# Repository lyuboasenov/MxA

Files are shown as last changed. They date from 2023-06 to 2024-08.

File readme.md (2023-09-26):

# MxA

MxA is a portable BLE-enabled strain gauge that can be used for weight-free training as well as testing/assessment.

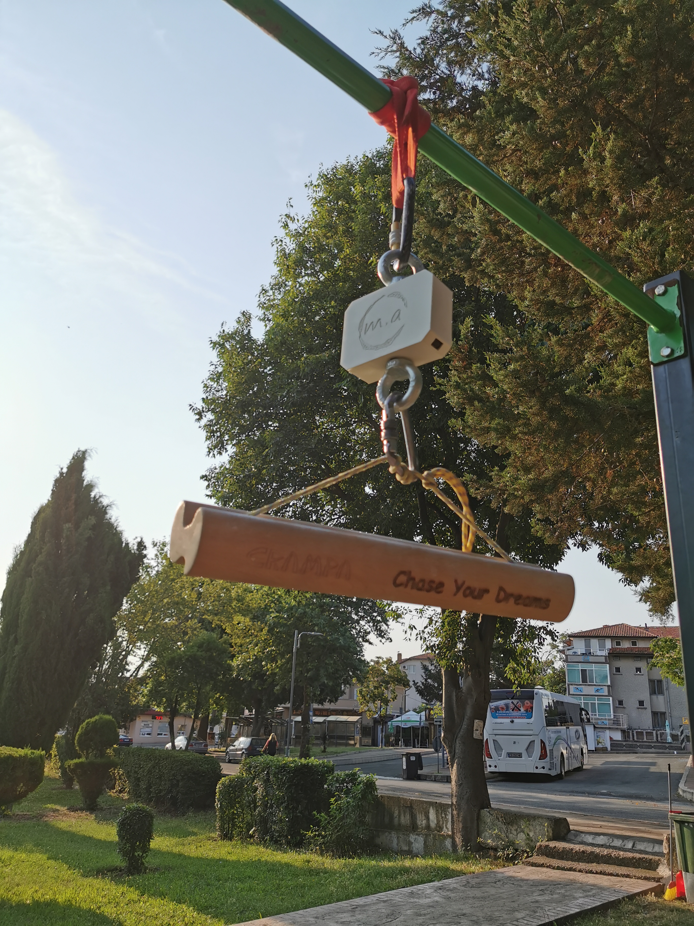
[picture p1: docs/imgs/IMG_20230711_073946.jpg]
In action


## Hardware technical specification

The hardware is based on ESP32-WROOM module, HX711 amplifier and S-type strain gauge.

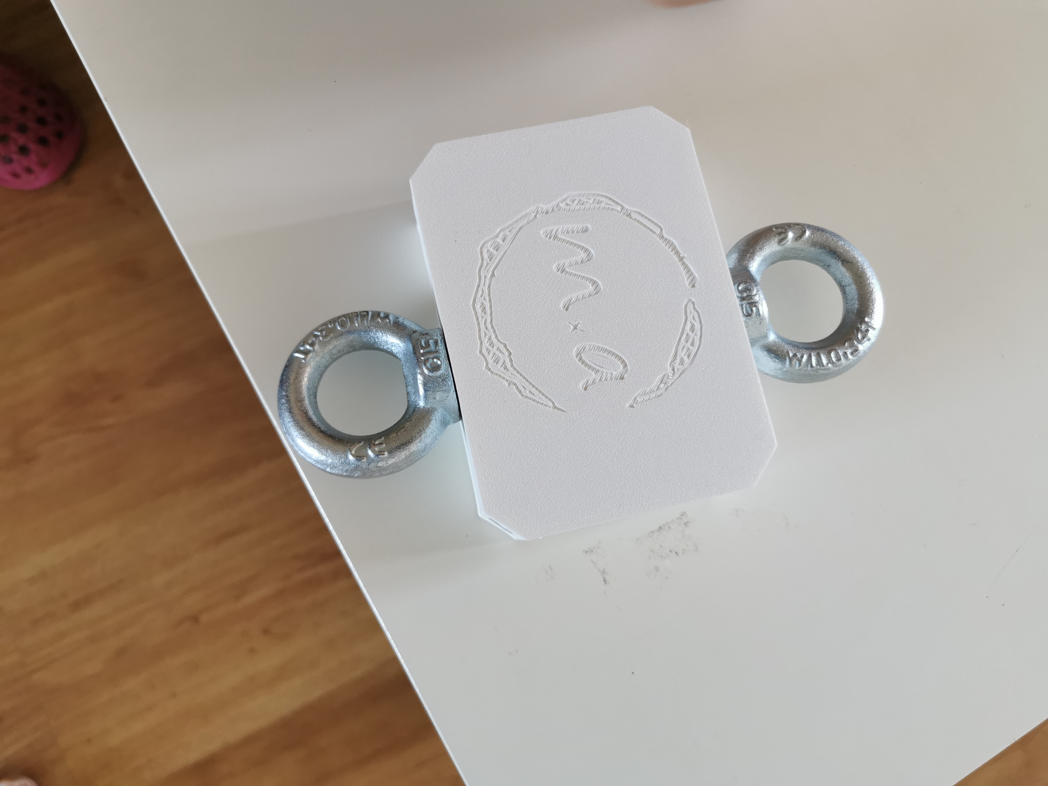
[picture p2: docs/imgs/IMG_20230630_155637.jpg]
Assembled device

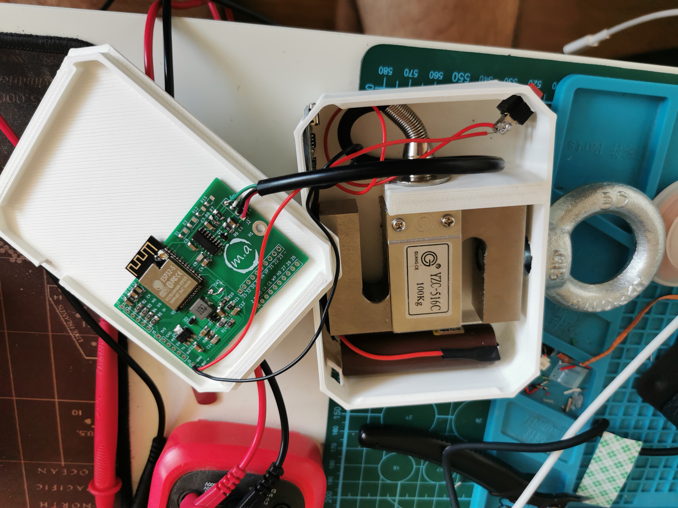
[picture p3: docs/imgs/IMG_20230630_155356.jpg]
Opened


[Read more...](docs/hardware.md)

**DIY** You can assemble the device from pre-built modules
[DIY](docs/diy.md)

## Firmware

[Read more...](docs/firmware.md)

## Mobile application

*TBA*

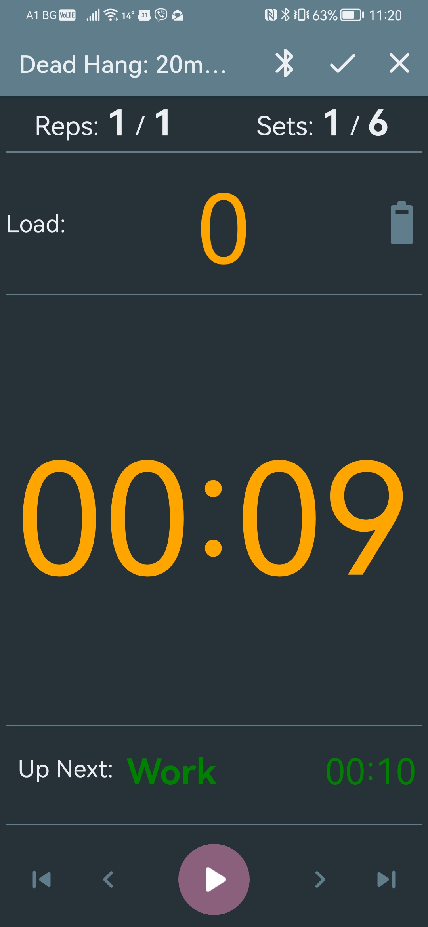
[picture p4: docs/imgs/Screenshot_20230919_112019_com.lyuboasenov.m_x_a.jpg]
Timer

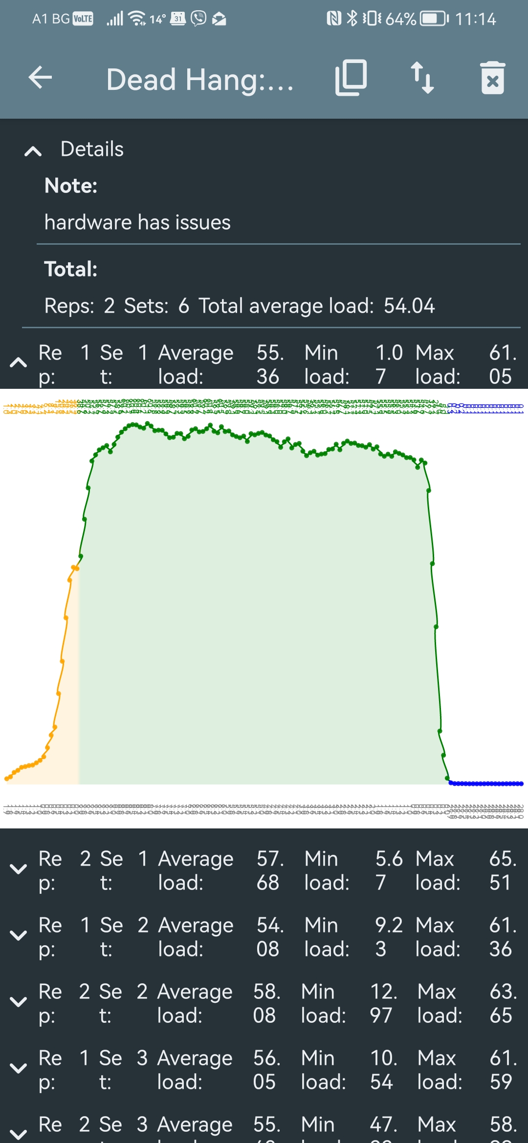
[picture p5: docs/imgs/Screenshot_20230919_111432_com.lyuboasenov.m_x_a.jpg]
Repetition diagram


[Read more...](docs/mobile-app.md)

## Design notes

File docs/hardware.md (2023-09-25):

# Hardware

The hardware is based on [ESP32-WROOM module](https://www.aliexpress.com/item/32840441199.html), [HX711](https://www.aliexpress.com/item/1005004493775451.html) amplifier and [S-type strain gauge](https://www.aliexpress.com/item/32866914213.html).

The power is supplied by a single [18650 battery](https://www.aliexpress.com/item/32821524948.html) and a [TP4056 module](https://www.aliexpress.com/item/1005004427739715.html) for battery charging.

## Schematic

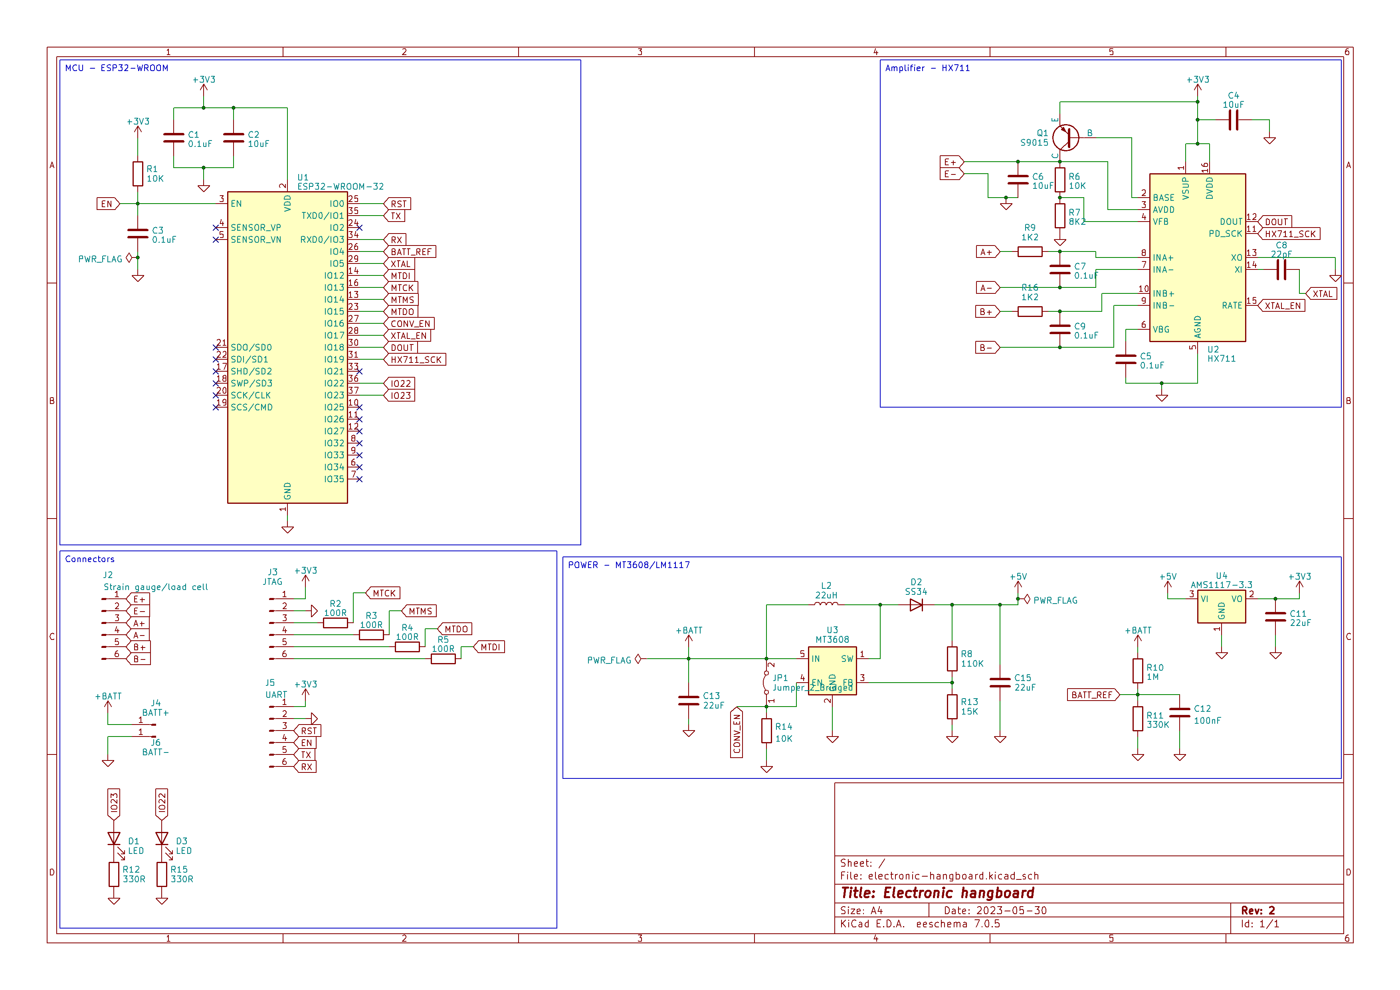
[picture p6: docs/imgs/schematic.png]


## PCB

### PCB v2 image

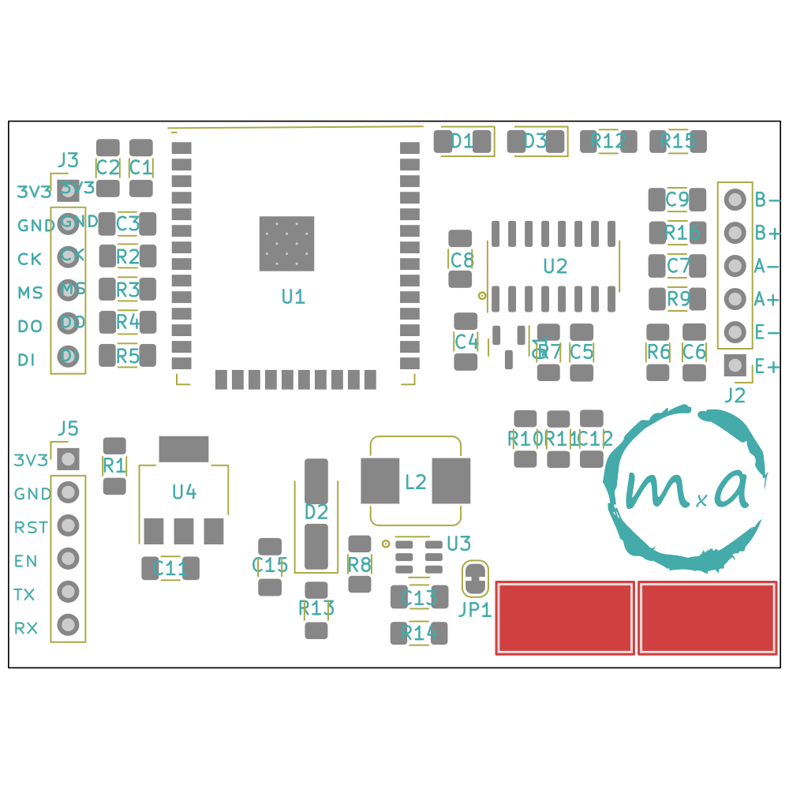
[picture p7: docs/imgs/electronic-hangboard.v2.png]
Board image


### Old PCB revisions

PCB old - white + new - green

## HX711

Increasing HX711 sampling rate [youtube](https://www.youtube.com/watch?v=Rp_M0NbDSpo)

## BOM

null|Sourced|Value|Footprint|Quantity|
|---|-------|-----|---------|--------|
1|C1, C3, C5, C7, C9, C12|100nF|C_1206_3216Metric_Pad1.33x1.80mm_HandSolder|6
2|C2, C4, C6|10uF|C_1206_3216Metric_Pad1.33x1.80mm_HandSolder|3
3|C11, C13, C15|22uF|C_1206_3216Metric_Pad1.33x1.80mm_HandSolder|3
4|C8|22pF|C_1206_3216Metric_Pad1.33x1.80mm_HandSolder|1
5|R2, R3, R4, R5|100R|R_1206_3216Metric_Pad1.30x1.75mm_HandSolder|4
6|R1, R6, R14|10K|R_1206_3216Metric_Pad1.30x1.75mm_HandSolder|3
7|R9, R16|1K2|R_1206_3216Metric_Pad1.30x1.75mm_HandSolder|2
8|R12, R15|330R|R_1206_3216Metric_Pad1.30x1.75mm_HandSolder|2
9|R7|8K2|R_1206_3216Metric_Pad1.30x1.75mm_HandSolder|1
10|R8|110K|R_1206_3216Metric_Pad1.30x1.75mm_HandSolder|1
11|R10|1M|R_1206_3216Metric_Pad1.30x1.75mm_HandSolder|1
12|R11|330K|R_1206_3216Metric_Pad1.30x1.75mm_HandSolder|1
13|R13|15K|R_1206_3216Metric_Pad1.30x1.75mm_HandSolder|1
14|L2|22uH|L_Bourns_SRP7028A_7.3x6.6mm|1
15|D1, D3|LED|D_1206_3216Metric_Pad1.42x1.75mm_HandSolder|2
16|D2|SS34|D_SMA_Handsoldering|1
17|U1|ESP32-WROOM-32|ESP32-WROOM-32|1
18|U2|HX711|SOP-16_3.9x9.9mm_P1.27mm|1
19|U3|MT3608|SOT-23-6|1
20|U4|AMS1117-3.3|SOT-223-3_TabPin2|1
21|JP1|Jumper_2_Bridged|SolderJumper-2_P1.3mm_Bridged_RoundedPad1.0x1.5mm|1
22|Q1|S9015|SOT-23|1
23|J4, J6|Conn_01x01_Pin|SolderWirePad_1x01_SMD_5x10mm|2
24|J2|Conn_01x04_Pin|PinHeader_1x06_P2.54mm_Vertical|1
25|J3|JTAG|PinHeader_1x06_P2.54mm_Vertical|1
26|J5|UART|PinHeader_1x06_P2.54mm_Vertical|1

## Images

Assembled device
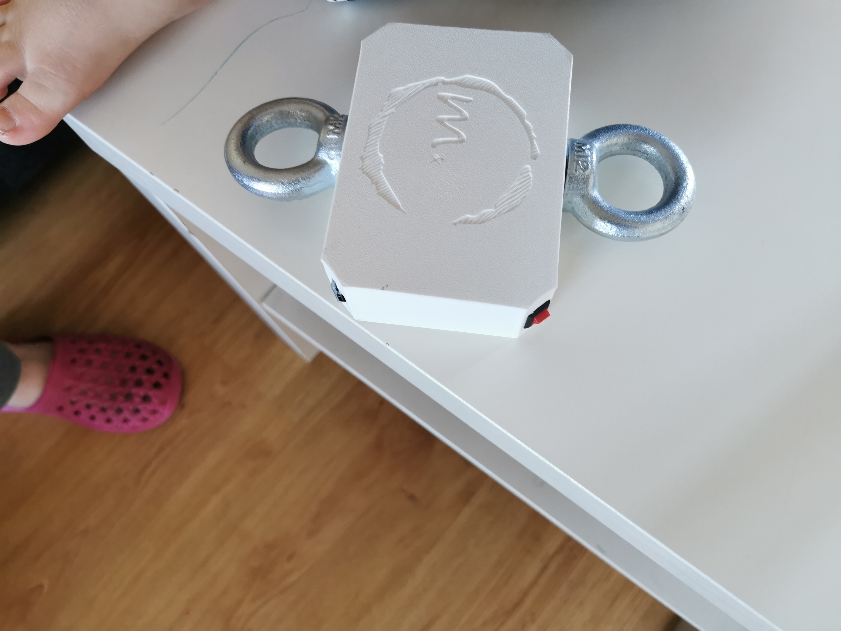
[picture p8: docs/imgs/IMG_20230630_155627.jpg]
Assembled device 2

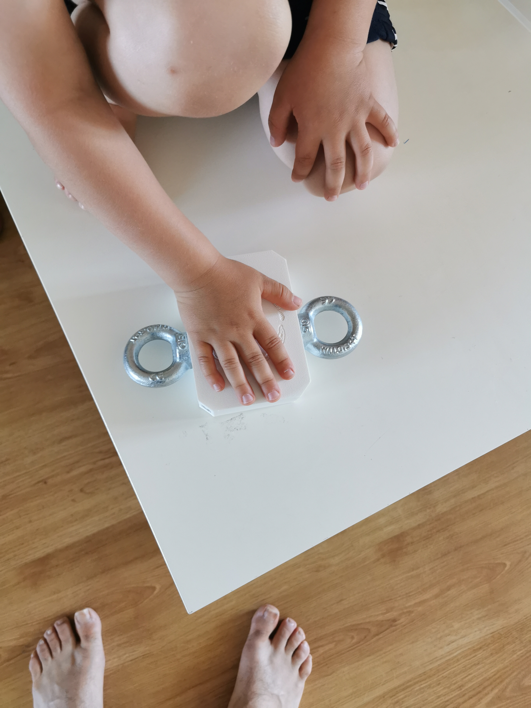
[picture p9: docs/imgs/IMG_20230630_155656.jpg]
Size reference

Opened
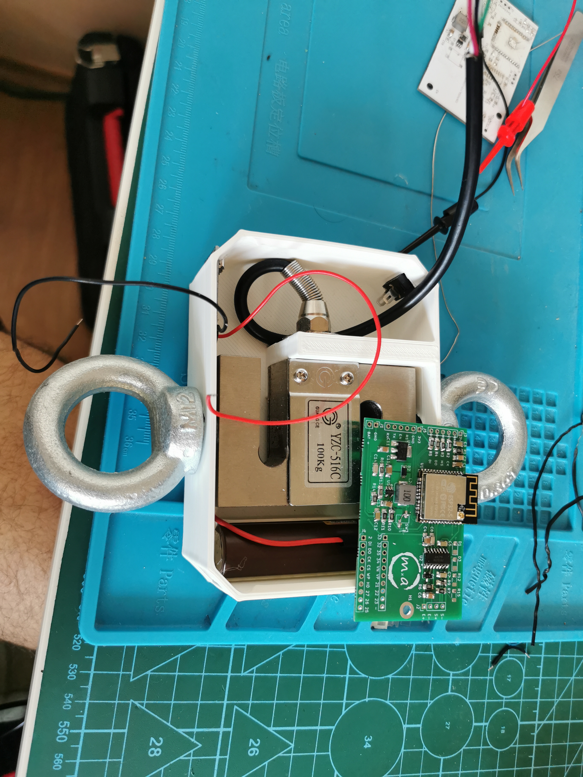
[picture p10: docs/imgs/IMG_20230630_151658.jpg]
Opened 2

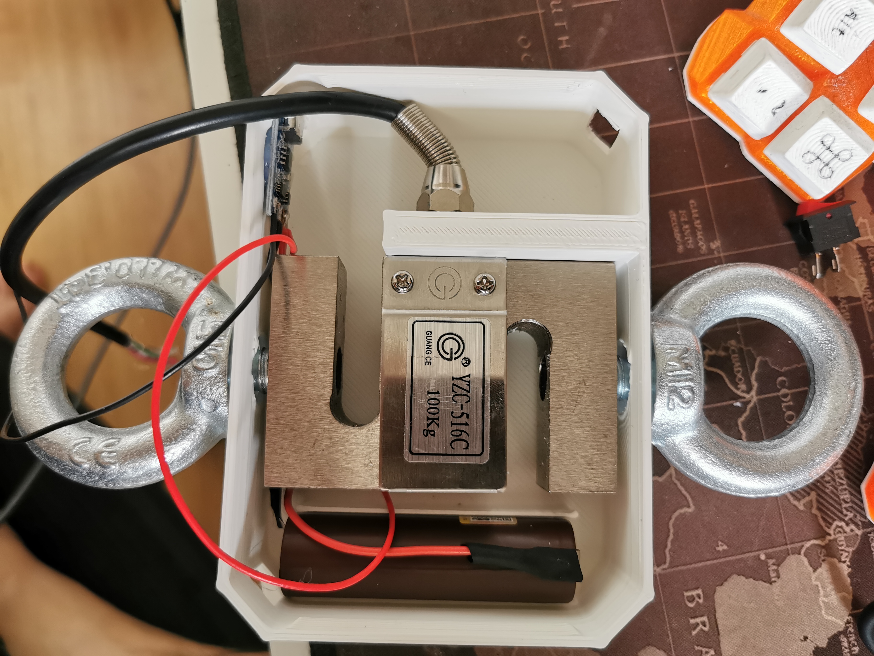
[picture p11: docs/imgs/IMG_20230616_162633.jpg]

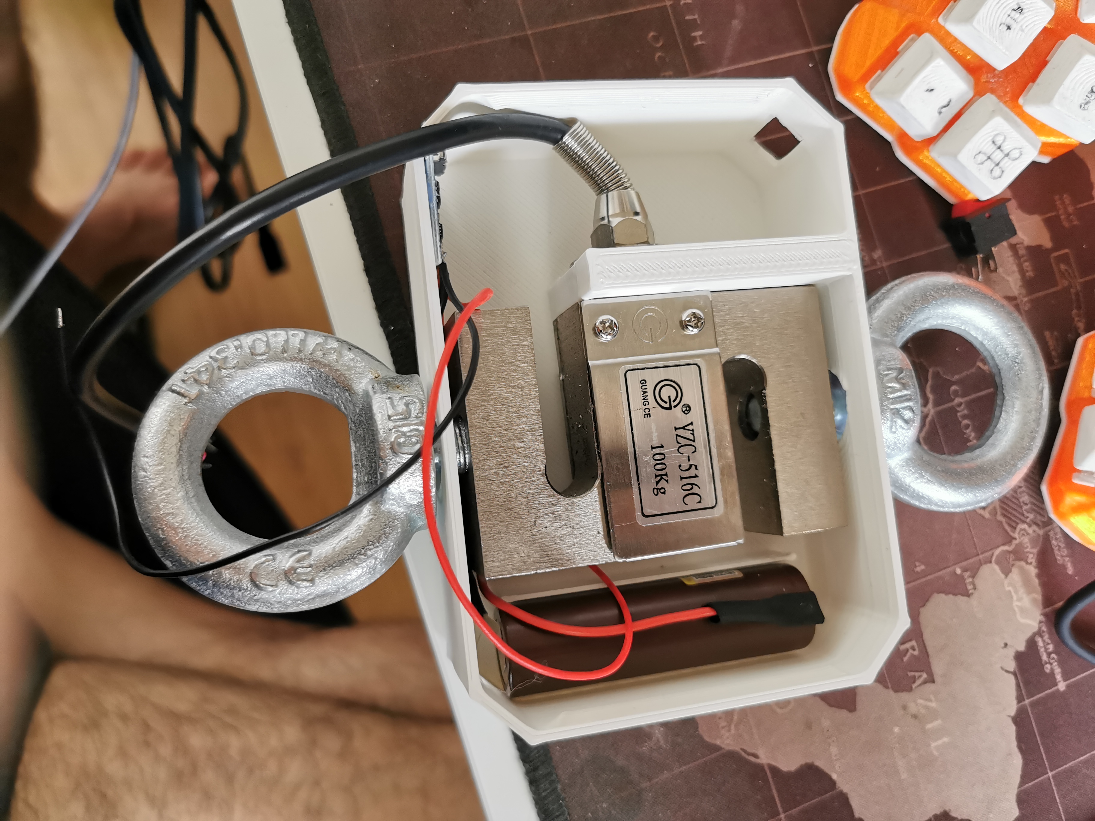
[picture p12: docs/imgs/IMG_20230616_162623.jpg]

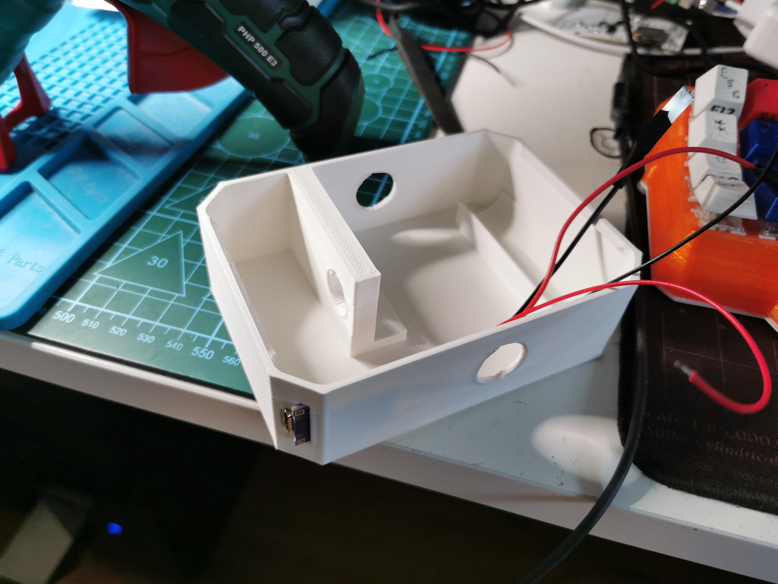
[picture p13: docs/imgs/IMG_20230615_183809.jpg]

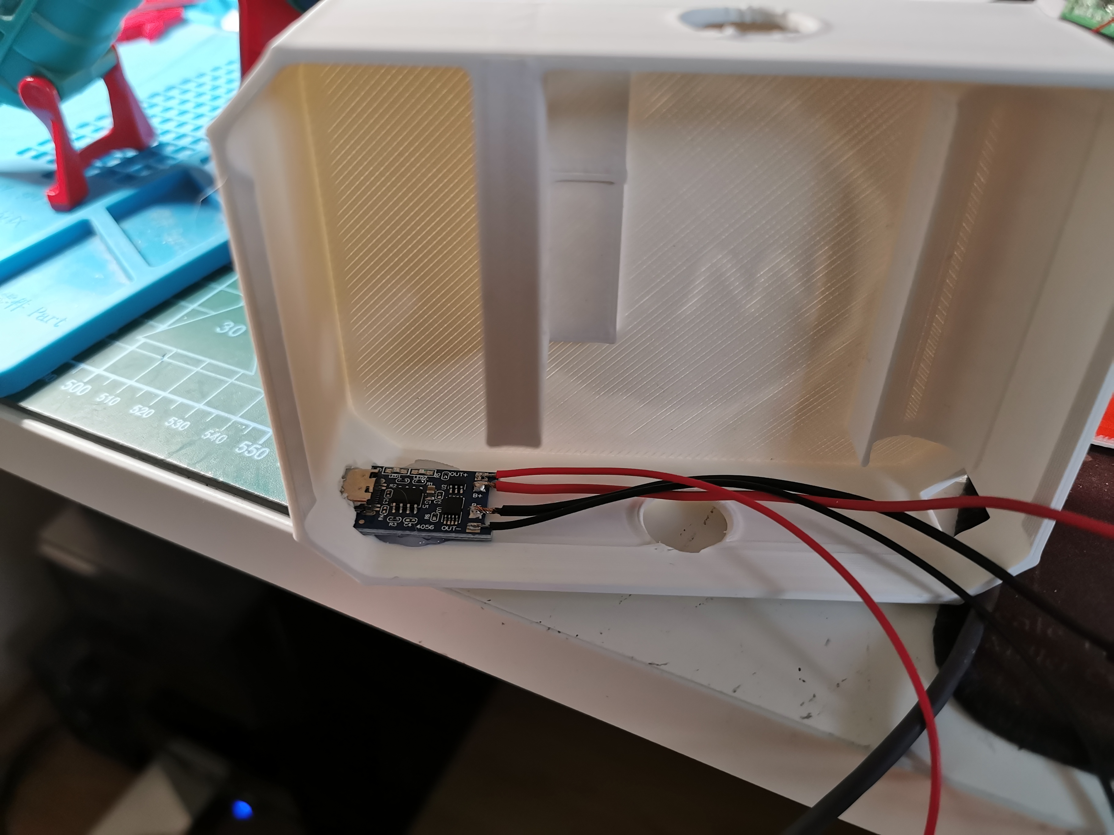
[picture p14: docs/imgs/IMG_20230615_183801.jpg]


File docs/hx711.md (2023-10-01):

# HX711

If HX711 module is used, it should be "upgraded" to boost it sampling rate and make it 3v3 compatible.

1. To make the module 3v3 compatible the R1 feedback voltage divider resistor should be substituted from 20K to 10K.
2. GND pin should be connected to either E- pin or to HX711's pin 5.
3. RATE (15) pin can be pulled up to increase the output rate from 10 Hz (LOW) to 80 Hz (HIGH)
4. A square ware clock signal can be fed into XI (14) through 22pF capacitor to control output data rate:
   1. RATE (15) LOW: fclk/1,105,920
   2. RATE (15) HIGH: fclk/138,240

Ref: [youtube](https://www.youtube.com/watch?v=Rp_M0NbDSpo)

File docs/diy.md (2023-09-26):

# DIY

You can assemble the device from pre-built modules. This build would be bulkier. It also would take fewer samples-per-second if the HX711 is left unmodified.

## Schematic

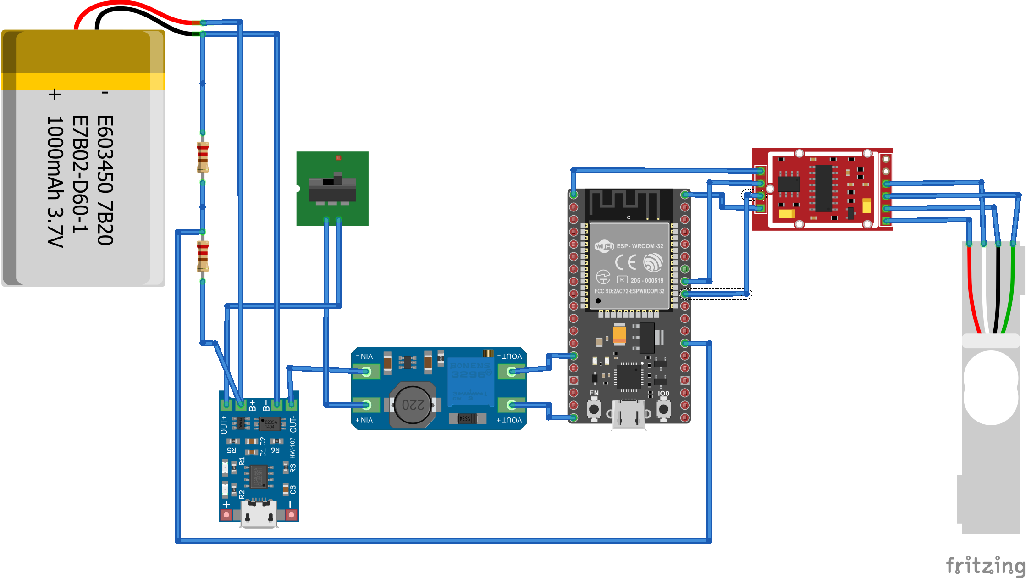
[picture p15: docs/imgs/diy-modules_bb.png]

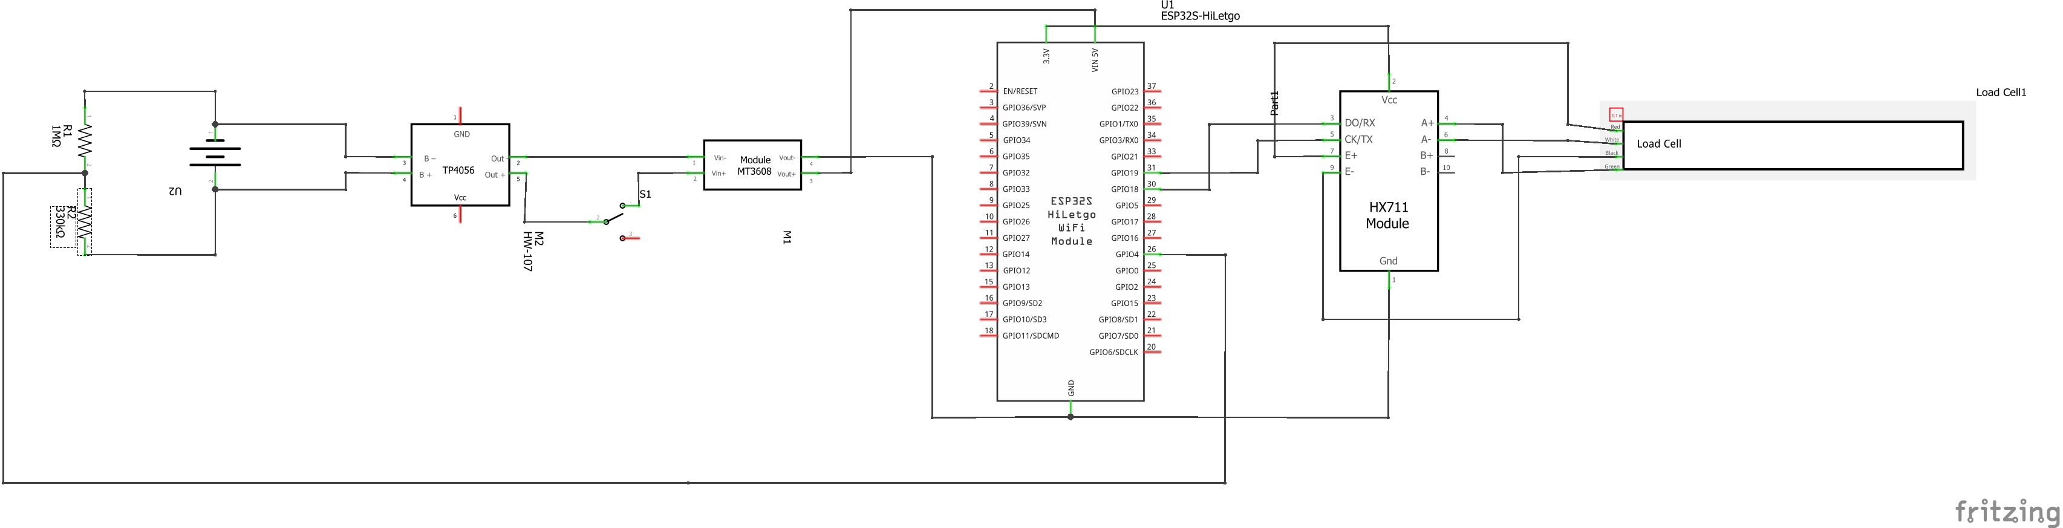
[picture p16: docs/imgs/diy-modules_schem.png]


## BOM

### MCU

[ESP32](https://www.aliexpress.com/item/1005005704190069.html)

### Measurement

[HX711](https://www.aliexpress.com/item/1005004493775451.html)
[S-type strain gauge](https://www.aliexpress.com/item/32866914213.html).

### Power

[MT3808](https://www.aliexpress.com/item/1005005682216062.html)
[18650 battery](https://www.aliexpress.com/item/32821524948.html)
[TP4056 module](https://www.aliexpress.com/item/1005004427739715.html)

### other

[Switch SPST](https://www.aliexpress.com/item/4001165826718.html)

## Images

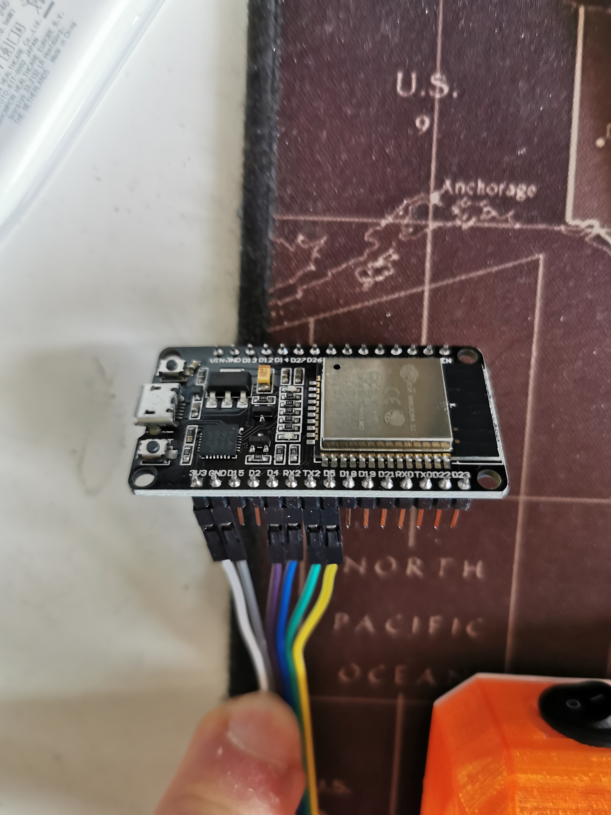
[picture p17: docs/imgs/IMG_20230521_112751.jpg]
MCU

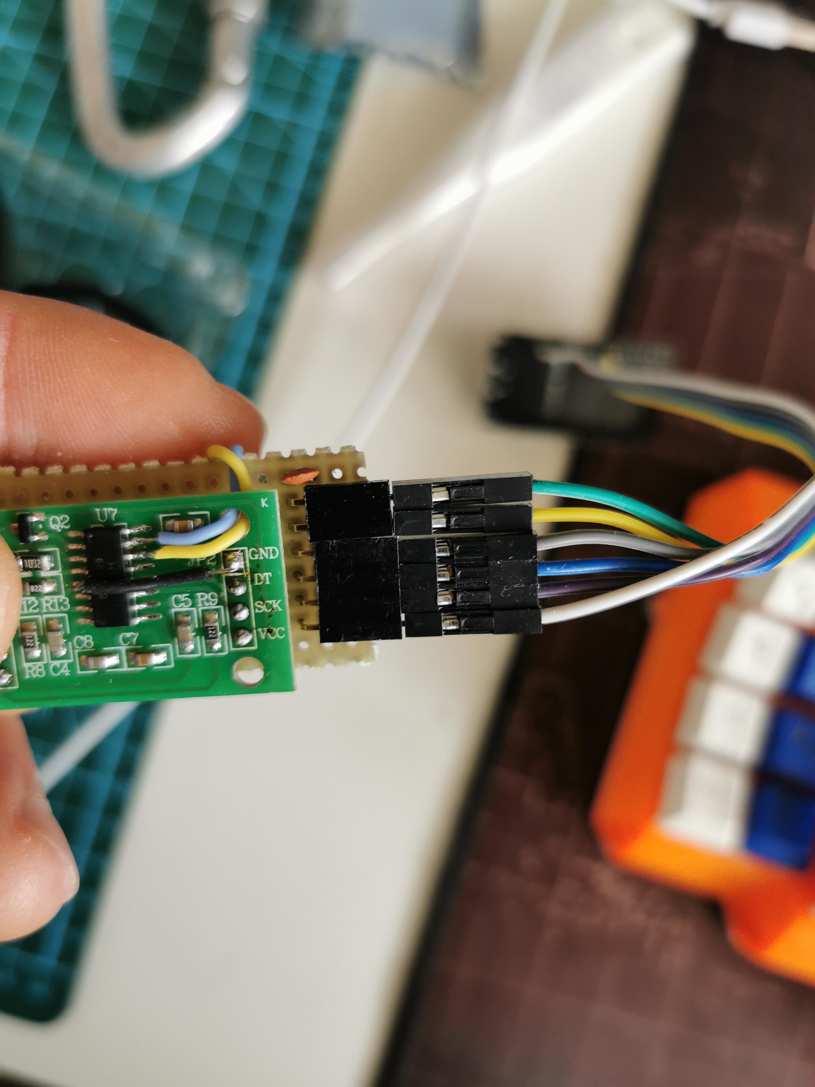
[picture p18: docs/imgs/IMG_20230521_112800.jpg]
HX711 fix top

HX711
MCU
HX711 bottom

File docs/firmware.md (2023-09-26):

# Firmware

The firmware is build using C/C++ [Arduino framework](https://www.arduino.cc/reference/en/libraries/) and [PlatformIO](https://platformio.org/).

## Firmware components

The firmware consists of these components:

### Battery level

This component is responsible for getting battery level in percent.

### BLE

This component is responsible for publishing the BLE services that broadcast the collected data and receive data for calibrating the device.

#### BLE services

The device published two BLE services.

##### Weight service - 0x181D

This service reports measured weight. Or if you write a value to this service, the calibration process is run.

##### Weight service - 0x180F

This service reports battery level.

### Load cell

This component is HAL (hardware abstraction layer) over the amplifier and bogde HX711 library.

### LED

This component is responsible for controlling the indicator LEDs.

There are two LEDs on the board. When the device is powered and is not paired the "red" LED fades in and out. When the device is paired the "red" LED stops fading and the "green" one starts fading in and out.

## Global configuration

The firmware can be customized by setting these global variables:

### LOAD_CELL_DOUT_PIN

The ESP32 pin connected to HX711 DOUT pin.

### LOAD_CELL_SCK_PIN

The ESP32 pin connected to HX711 PD_SCK pin.

### LOAD_CELL_XTAL_PIN

The ESP32 pin connected to HX711 XI pin.

### LOAD_CELL_XTAL_FREQ

The frequency fed to HX711 in Hz. Values 1 - 20MHz.

### LOAD_CELL_XTAL_CHANNEL

The [ESP timer channel](https://docs.espressif.com/projects/esp-idf/en/latest/esp32/api-reference/peripherals/ledc.html) used to generate the clock signal for HX711. Valid values 0 - 7.

### LOAD_CELL_XTAL_ENABLE_PIN

The ESP32 pin connected to HX711 RATE pin.

### BATTERY_LEVEL_PIN

The ESP32 pin used to measure the battery level.

### BATTERY_LEVEL_MAX_VALUE_ADC

The ADC value ESP32 will measure when the battery is full.

### BATTERY_LEVEL_MIN_VALUE_ADC

The ADC value ESP32 will measure when the battery is empty.

### BATTERY_LEVEL_CHECK_INTERVAL_MILLIS

The interval for measuring battery level in milliseconds.

### LED_RED_PIN

The ESP32 pin connected to the red led.

### LED_GREEN_PIN

The ESP32 pin connected to the green led.

### LED_FADE_AMOUNT

The value by which led intensity is altered when fading.

## Flashing firmware

The firmware can be flashed to the ESP32-WROOM module either through serial port (UART) or JTAG.

**Note** The first firmware flashing on a ESP32-WROOM module can only be done using the serial port [espressif docs](https://docs.espressif.com/projects/esp-idf/en/latest/esp32/api-guides/jtag-debugging/tips-and-quirks.html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).

There is a point called:
**JTAG and ESP32-WROOM-32 AT firmware Compatibility Issue**

With this text:
**The ESP32-WROOM series of modules come pre-flashed with AT firmware. This firmware configures the pins GPIO12 to GPIO15 as SPI slave interface, which makes using JTAG impossible.**

**To make JTAG available, build new firmware that is not using pins GPIO12 to GPIO15 dedicated to JTAG communication. After that, flash the firmware onto your module.**

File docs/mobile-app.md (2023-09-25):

# Mobile application

*TBA*

Timer
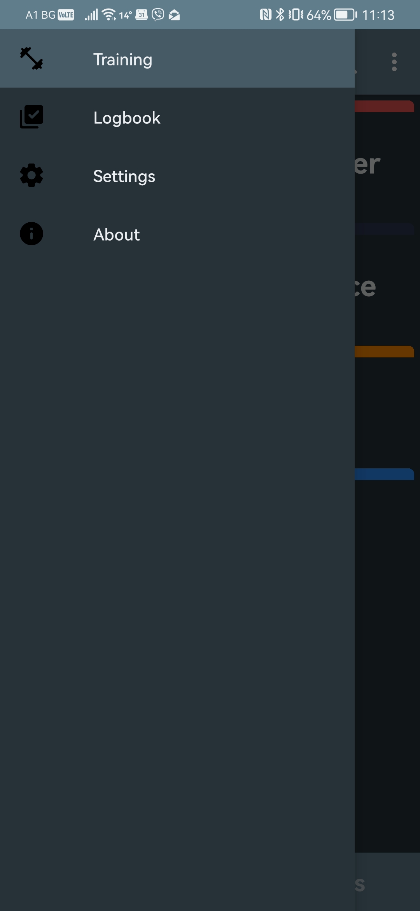
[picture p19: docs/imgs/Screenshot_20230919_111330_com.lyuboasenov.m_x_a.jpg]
Menu

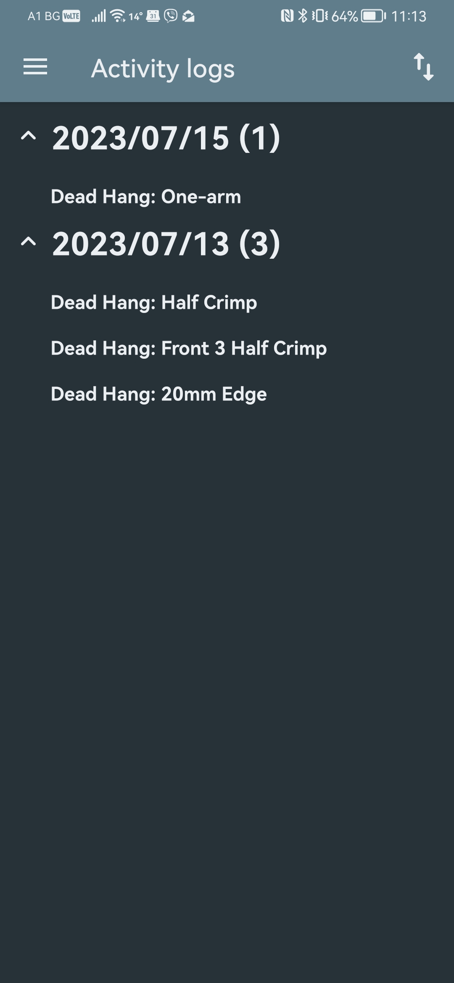
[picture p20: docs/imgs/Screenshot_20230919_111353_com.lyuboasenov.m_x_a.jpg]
Log

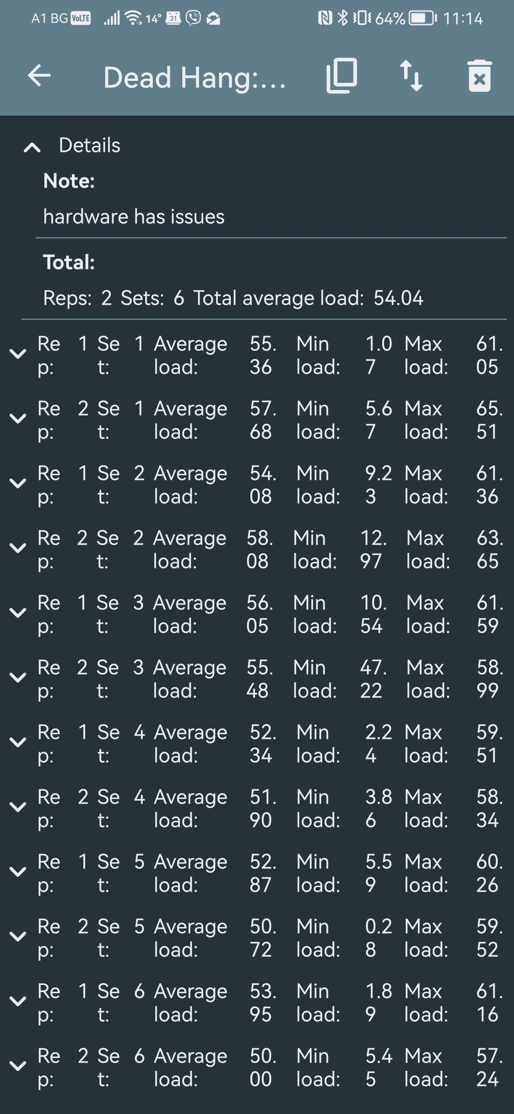
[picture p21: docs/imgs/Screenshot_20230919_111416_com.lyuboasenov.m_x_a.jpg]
Activity record

Repetition diagram

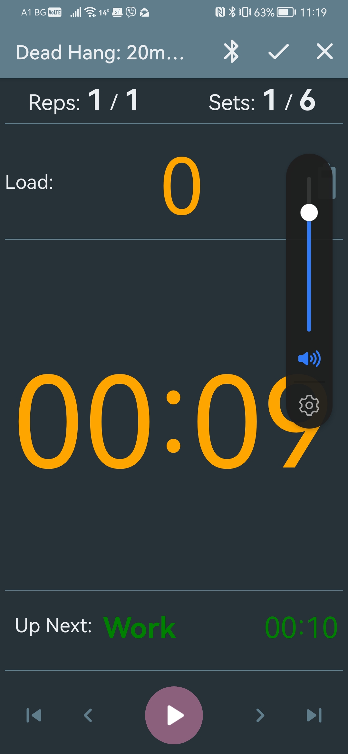
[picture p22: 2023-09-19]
docs/imgs/Screenshot_20230919_111915_com.lyuboasenov.m_x_a.jpg

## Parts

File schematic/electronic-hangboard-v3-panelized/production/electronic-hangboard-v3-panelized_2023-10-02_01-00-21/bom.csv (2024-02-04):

Designator | Footprint | Quantity | Value | LCSC Part #
C1_4, C1_3, C1_2, C1, C3_4, C3_3, C3_2, C3, C5_4, C5_3, C5_2, C5, C7_4, C7_3, C7_2, C7, C9_4, C9_3, C9_2, C9 | 1206 | 20 | 0.1uF
C10_4, C10_3, C10_2, C10, C11_4, C11_3, C11_2, C11 | 1206 | 8 | 22uF
C12_4, C12_3, C12_2, C12 | 1206 | 4 | 100nF
C2_4, C2_3, C2_2, C2, C4_4, C4_3, C4_2, C4, C6_4, C6_3, C6_2, C6 | 1206 | 12 | 10uF
C8_4, C8_3, C8_2, C8 | 1206 | 4 | 22pF
D1_4, D1_3, D1_2, D1, D3_4, D3_3, D3_2, D3 | 1206 | 8 | LED
J2_4, J2_3, J2_2, J2 | PinHeader_1x06_P2.54mm_Vertical | 4 | Strain gauge/load cell
J3_4, J3_3, J3_2, J3 | PinHeader_1x06_P2.54mm_Vertical | 4 | JTAG
J4_4, J4_3, J4_2, J4 | 2x5_solder_wire_pad | 4 | BATT+
J6_4, J6_3, J6_2, J6 | 2x5_solder_wire_pad | 4 | BATT-
Q1_4, Q1_3, Q1_2, Q1 | SOT-23 | 4 | S9015
R1_4, R1_3, R1_2, R1, R6_4, R6_3, R6_2, R6 | 1206 | 8 | 10K
R10_4, R10_3, R10_2, R10 | 1206 | 4 | 1M
R11_4, R11_3, R11_2, R11 | 1206 | 4 | 330K
R12_4, R12_3, R12_2, R12, R15_4, R15_3, R15_2, R15 | 1206 | 8 | 330R
R16_4, R16_3, R16_2, R16, R9_4, R9_3, R9_2, R9 | 1206 | 8 | 1K2
R2_4, R2_3, R2_2, R2, R3_4, R3_3, R3_2, R3, R4_4, R4_3, R4_2, R4, R5_4, R5_3, R5_2, R5 | 1206 | 16 | 100R
R7_4, R7_3, R7_2, R7 | 1206 | 4 | 8K2
U1_4, U1_3, U1_2, U1 | ESP32-WROOM-32 | 4 | ESP32-WROOM-32
U2_4, U2_3, U2_2, U2 | SOP-16_3.9x9.9mm_P1.27mm | 4 | HX711
U4_4, U4_3, U4_2, U4 | SOT-223-3_TabPin2 | 4 | AMS1117-3.3

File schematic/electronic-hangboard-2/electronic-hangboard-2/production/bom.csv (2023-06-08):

Designator | Footprint | Quantity | Value | LCSC Part #
_17, _16, _15, _14, _13, _12, _11, _10, _9, _8, _7, _6, _5, _4, _3, _2, |  | 17
C1_2, C1, C3_2, C3, C5_2, C5, C7_2, C7 | 1206 | 8 | 0.1uF
C10_2, C10 | 1206 | 2 | 68uF
C11_2, C11 | 1206 | 2 | 22uF
C12_2, C12 | 1206 | 2 | 100nF
C2_2, C2, C4_2, C4, C6_2, C6, C9_2, C9 | 1206 | 8 | 10uF
C8_2, C8 | 1206 | 2 | 22pF
D1_2, D1 | D_SOD-123 | 2 | MBR0520LT1
H1_2, H1, H2_2, H2, H3_2, H3 | MountingHole_3.2mm_M3 | 6 | MountingHole
J1_2, J1 | PinHeader_1x03_P2.54mm_Vertical | 2 | UART
J2_2, J2 | SolderWire-0.1sqmm_1x04_P3.6mm_D0.4mm_OD1mm_Relief | 2 | Load cell
J3_2, J3 | PinHeader_1x07_P2.54mm_Vertical | 2 | JTAG
J4_2, J4 | SolderWire-0.1sqmm_1x02_P3.6mm_D0.4mm_OD1mm | 2 | Battery
L1_2, L1 | L_Bourns_SRP7028A_7.3x6.6mm | 2 | CR54−220MC - 22uH
Q1_2, Q1 | SOT-23 | 2 | 2N7002
R1_2, R1 | 1206 | 2 | R
R10_2, R10 | 1206 | 2 | 1M
R11_2, R11 | 1206 | 2 | 330K
R12_2, R12, R6_2, R6 | 1206 | 4 | 10K
R2_2, R2, R3_2, R3, R4_2, R4, R5_2, R5, R8_2, R8, R9_2, R9 | 1206 | 12 | 100R
R7_2, R7 | 1206 | 2 | 8K2
SW1_2, SW1 | SW_Push_1P1T_NO_6x6mm_H9.5mm | 2 | RESET
SW2_2, SW2 | SW_Push_1P1T_NO_6x6mm_H9.5mm | 2 | POWER_ON
U1_2, U1 | ESP32-WROOM-32 | 2 | ESP32-WROOM-32
U2_2, U2 | SOP-16_3.9x9.9mm_P1.27mm | 2 | HX711
U3_2, U3 | SOT-23-5_HandSoldering | 2 | NCP1400A
U4_2, U4 | SOT-223-3_TabPin2 | 2 | AMS1117-3.3

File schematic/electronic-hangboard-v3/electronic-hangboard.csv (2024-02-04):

Id | Designator | Footprint | Quantity | Designation | Supplier and ref
1 | R2,R4,R3,R5 | R_1206_3216Metric_Pad1.30x1.75mm_HandSolder | 4 | 100R
2 | R11 | R_1206_3216Metric_Pad1.30x1.75mm_HandSolder | 1 | 330K
3 | C10,C11 | C_1206_3216Metric_Pad1.33x1.80mm_HandSolder | 2 | 22uF
4 | D1,D3 | D_1206_3216Metric_Pad1.42x1.75mm_HandSolder | 2 | LED
5 | C12 | C_1206_3216Metric_Pad1.33x1.80mm_HandSolder | 1 | 100nF
6 | C2,C6,C4 | C_1206_3216Metric_Pad1.33x1.80mm_HandSolder | 3 | 10uF
7 | U1 | ESP32-WROOM-32 | 1 | ESP32-WROOM-32
8 | Q1 | SOT-23 | 1 | S9015
9 | C5,C7,C1,C9,C3 | C_1206_3216Metric_Pad1.33x1.80mm_HandSolder | 5 | 0.1uF
10 | J3 | PinHeader_1x06_P2.54mm_Vertical | 1 | JTAG
11 | U2 | SOP-16_3.9x9.9mm_P1.27mm | 1 | HX711
12 | J6 | 2x5_solder_wire_pad | 1 | BATT-
13 | R1,R6 | R_1206_3216Metric_Pad1.30x1.75mm_HandSolder | 2 | 10K
14 | R12,R15 | R_1206_3216Metric_Pad1.30x1.75mm_HandSolder | 2 | 330R
15 | R7 | R_1206_3216Metric_Pad1.30x1.75mm_HandSolder | 1 | 8K2
16 | R16,R9 | R_1206_3216Metric_Pad1.30x1.75mm_HandSolder | 2 | 1K2
17 | U4 | SOT-223-3_TabPin2 | 1 | AMS1117-3.3
18 | J2 | PinHeader_1x06_P2.54mm_Vertical | 1 | Strain gauge/load cell
19 | J4 | 2x5_solder_wire_pad | 1 | BATT+
20 | C8 | C_1206_3216Metric_Pad1.33x1.80mm_HandSolder | 1 | 22pF
21 | R10 | R_1206_3216Metric_Pad1.30x1.75mm_HandSolder | 1 | 1M

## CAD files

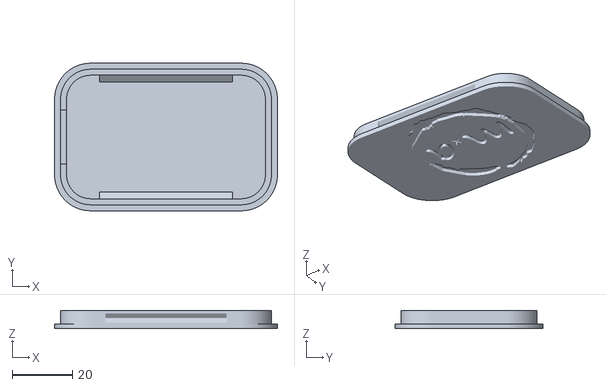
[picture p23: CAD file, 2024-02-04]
enclosure/mxa_v3_bottom.stl
74.0 x 49.0 x 6.00

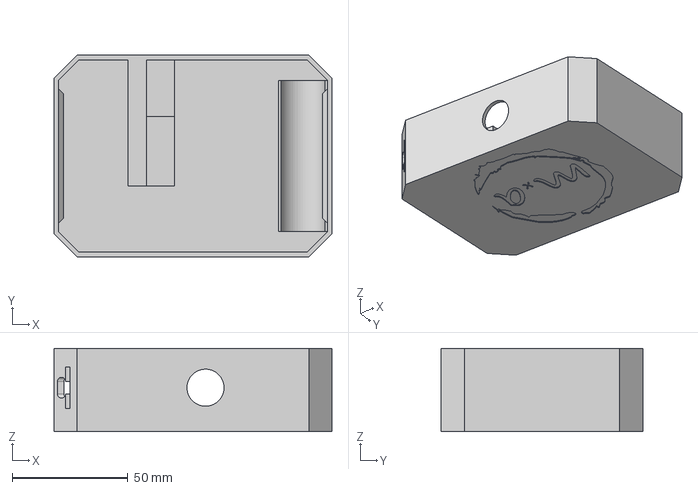
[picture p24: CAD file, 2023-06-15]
resources/f=ma box v10.step
120.0 x 87.0 x 36.0 mm

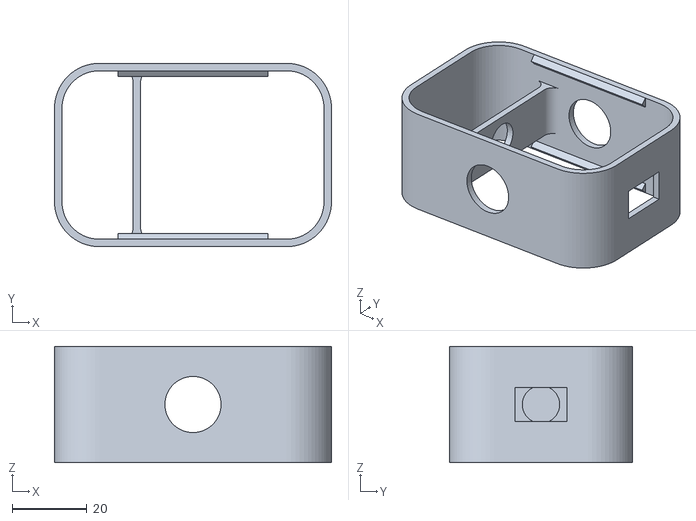
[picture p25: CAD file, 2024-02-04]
enclosure/mxa_v3_side.stl
74.0 x 49.0 x 31.0

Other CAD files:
enclosure/mxa_v3_top.stl

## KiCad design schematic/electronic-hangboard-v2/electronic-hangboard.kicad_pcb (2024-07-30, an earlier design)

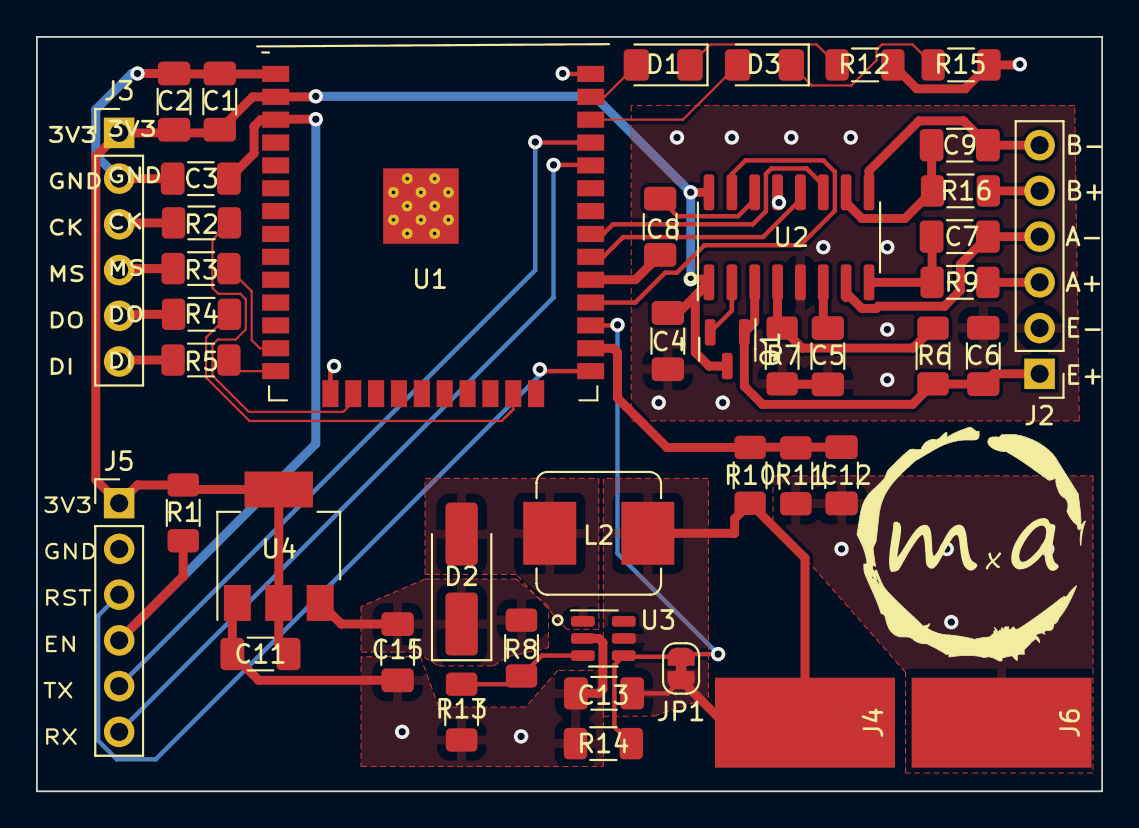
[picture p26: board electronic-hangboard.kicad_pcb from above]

Board: 2 copper layers, 59.2 x 41.9 mm, 44 parts (0 on the bottom side), 39 nets.

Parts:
C1, C3, C5, C7, C9: 0.1uF; C_1206_3216Metric_Pad1.33x1.80mm_HandSolder
C2, C4, C6: 10uF; C_1206_3216Metric_Pad1.33x1.80mm_HandSolder
C8: 22pF; C_1206_3216Metric_Pad1.33x1.80mm_HandSolder
C11, C13, C15: 22uF; C_1206_3216Metric_Pad1.33x1.80mm_HandSolder
C12: 100nF; C_1206_3216Metric_Pad1.33x1.80mm_HandSolder
D1, D3: LED; D_1206_3216Metric_Pad1.42x1.75mm_HandSolder
D2: SS34; D_SMA_Handsoldering
J2: Conn_01x04_Pin; PinHeader_1x06_P2.54mm_Vertical
J3: JTAG; PinHeader_1x06_P2.54mm_Vertical
J4, J6: Conn_01x01_Pin; SolderWirePad_1x01_SMD_5x10mm
J5: UART; PinHeader_1x06_P2.54mm_Vertical
JP1: Jumper_2_Bridged; SolderJumper-2_P1.3mm_Bridged_RoundedPad1.0x1.5mm
L2: 22uH; L_Bourns_SRP7028A_7.3x6.6mm
Q1: S9015; SOT-23
R1, R6, R14: 10K; R_1206_3216Metric_Pad1.30x1.75mm_HandSolder
R2, R3, R4, R5: 100R; R_1206_3216Metric_Pad1.30x1.75mm_HandSolder
R7: 8K2; R_1206_3216Metric_Pad1.30x1.75mm_HandSolder
R8: 110K; R_1206_3216Metric_Pad1.30x1.75mm_HandSolder
R9, R16: 1K2; R_1206_3216Metric_Pad1.30x1.75mm_HandSolder
R10: 1M; R_1206_3216Metric_Pad1.30x1.75mm_HandSolder
R11: 330K; R_1206_3216Metric_Pad1.30x1.75mm_HandSolder
R12, R15: 330R; R_1206_3216Metric_Pad1.30x1.75mm_HandSolder
R13: 15K; R_1206_3216Metric_Pad1.30x1.75mm_HandSolder
U1: ESP32-WROOM-32
U2: HX711; SOP-16_3.9x9.9mm_P1.27mm
U3: MT3608; SOT-23-6
U4: AMS1117-3.3; SOT-223-3_TabPin2

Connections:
+3V3: C1.1, C2.1, C4.1, C11.2, J3.1, J5.1, Q1.3 (E), R1.1, U1.2 (VDD), U2.1 (VSUP), U2.16 (DVDD), U4.2 (VO)
+5V: C15.2, D2.1 (K), R8.1, U4.3 (VI)
+BATT: C13.2, J4.1, JP1.2 (B), L2.1, R10.1, U3.5 (IN)
A+: J2.3, R9.1
A-: C7.2, J2.4, U2.7 (INA-)
B+: J2.5, R16.1
B-: C9.2, J2.6, U2.9 (INB-)
BATT_REF: C12.1, R10.2, R11.1, U1.26 (IO4)
CONV_EN: JP1.1 (A), R14.1, U1.27 (IO16), U3.4 (EN)
DOUT: U1.30 (IO18), U2.12 (DOUT)
E+: C6.2, J2.1, Q1.1 (C), R6.1, U2.3 (AVDD)
E-: C1.2, C2.2, C3.1, C4.2, C5.1, C6.1, C11.1, C12.2, C13.1, C15.1, J2.2, J3.2, J5.2, J6.1, R7.2, R11.2, R12.1, R13.2, R14.2, R15.2, U1.1 (GND), U1.15 (GND), U1.38 (GND), U1.39 (GND), U2.5 (AGND), U2.13 (XO), U3.2 (GND), U4.1 (GND)
EN: C3.2, J5.4, R1.2, U1.3 (EN)
HX711_SCK: U1.31 (IO19), U2.11 (PD_SCK)
IO22: D3.2 (A), U1.36 (IO22)
IO23: D1.2 (A), U1.37 (IO23)
MTCK: R2.2, U1.16 (IO13)
MTDI: R5.2, U1.14 (IO12)
MTDO: R4.2, U1.23 (IO15)
MTMS: R3.2, U1.13 (IO14)
unnamed: D1.1 (K), R12.2
unnamed: D2.2 (A), L2.2, U3.1 (SW)
unnamed: D3.1 (K), R15.1
unnamed: J3.3, R2.1
unnamed: J3.4, R3.1
unnamed: J3.5, R4.1
unnamed: J3.6, R5.1
unnamed: Q1.2 (B), U2.2 (BASE)
unnamed: C7.1, R9.2, U2.8 (INA+)
unnamed: C9.1, R16.2, U2.10 (INB+)
unnamed: C5.2, U2.6 (VBG)
unnamed: R6.2, R7.1, U2.4 (VFB)
unnamed: C8.1, U2.14 (XI)
unnamed: R8.2, R13.1, U3.3 (FB)
RST: J5.3, U1.25 (IO0)
RX: J5.6, U1.34 (RXD0/IO3)
TX: J5.5, U1.35 (TXD0/IO1)
XTAL: C8.2, U1.29 (IO5)
XTAL_EN: U1.28 (IO17), U2.15 (RATE)

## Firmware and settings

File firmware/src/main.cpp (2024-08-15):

#include <Arduino.h>

#include "Ble.h"
#include "LoadCell.h"
#include "BatteryLevel.h"
#include "Led.h"
#include "debug_print.h"

Ble _ble;
LoadCell _load_cell;
BatteryLevel _battery;
Led _led;

void setup() {
   #ifdef DEBUG_OUTPUT_ENABLED
   Serial.begin(115200);
   #endif

   DEBUG_OUTPUT(verbosity_t::info, "MAIN", "  _________________________________");
   DEBUG_OUTPUT(verbosity_t::info, "MAIN", "((                                  ))");
   DEBUG_OUTPUT(verbosity_t::info, "MAIN", " ))       MxA v.%d.%d.%d.%d (( ", SOFTWARE_VERSION_MAJOR, SOFTWARE_VERSION_MINOR, SOFTWARE_VERSION_PATCH, SOFTWARE_VERSION_BUILD);
   DEBUG_OUTPUT(verbosity_t::info, "MAIN", "((                                  ))");
   DEBUG_OUTPUT(verbosity_t::info, "MAIN", "  ----------------------------------  ");

   _load_cell.begin();
   _ble.begin();
   _battery.begin();
   _led.begin();

   _led.blink_red();
}

uint32_t last_battery_checked_at = 0;
float units;
void loop() {

   _ble.check_to_reconnect();

   if (_ble.had_received_weight()) {
      float received_weight = _ble.read_received_weight();
      _load_cell.set_units(received_weight);
   }

   units = _load_cell.get_units(5);

   if (_ble.connected()) {
      _ble.weight_notify(units);

      if (millis() - last_battery_checked_at > BATTERY_LEVEL_CHECK_INTERVAL_MILLIS) {
         _ble.battery_notify(_battery.get_level());
         last_battery_checked_at = millis();
      }

      DEBUG_OUTPUT(verbosity_t::debug, "MAIN", "%d %d", millis(), units);

      _led.turn_off_red();
      _led.blink_green();
   } else {
      DEBUG_OUTPUT(verbosity_t::debug, "MAIN", "Waiting for client");
      _led.blink_red();
      _led.turn_off_green();
   }
}

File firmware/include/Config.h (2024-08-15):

#pragma once

/**
 * @def SOFTWARE_VERSION_MAJOR
 * @brief Software version major number - year
 */
#ifndef SOFTWARE_VERSION_MAJOR
#define SOFTWARE_VERSION_MAJOR 24
#endif

/**
 * @def SOFTWARE_VERSION_MINOR
 * @brief Software version minor number - month
 */
#ifndef SOFTWARE_VERSION_MINOR
#define SOFTWARE_VERSION_MINOR 8
#endif

/**
 * @def SOFTWARE_VERSION_PATCH
 * @brief Software version patch number - day
 */
#ifndef SOFTWARE_VERSION_PATCH
#define SOFTWARE_VERSION_PATCH 15
#endif

/**
 * @def SOFTWARE_VERSION_BUILD
 * @brief Software version build number
 */
#ifndef SOFTWARE_VERSION_BUILD
#define SOFTWARE_VERSION_BUILD 1
#endif

/**
 * @def HARDWARE_VERSION_MAJOR
 * @brief Hardware version major number - electronics revision
 */
#ifndef HARDWARE_VERSION_MAJOR
#define HARDWARE_VERSION_MAJOR 2
#endif

/**
 * @def HARDWARE_VERSION_MINOR
 * @brief Hardware version major number - load cell index
 */
#ifndef HARDWARE_VERSION_MINOR
#define HARDWARE_VERSION_MINOR 100
#endif

/**
 * @def LOAD_CELL_DOUT_PIN
 * @brief The ESP32 pin connected to HX711 DOUT pin.
 */
#ifndef LOAD_CELL_DOUT_PIN
#define LOAD_CELL_DOUT_PIN 18
#endif

/**
 * @def LOAD_CELL_SCK_PIN
 * @brief The ESP32 pin connected to HX711 PD_SCK pin.
 */
#ifndef LOAD_CELL_SCK_PIN
#define LOAD_CELL_SCK_PIN 19
#endif

/**
 * @def LOAD_CELL_XTAL_PIN
 * @brief The ESP32 pin connected to HX711 XI pin.
 */
#ifndef LOAD_CELL_XTAL_PIN
#define LOAD_CELL_XTAL_PIN 5
#endif

/**
 * @def LOAD_CELL_XTAL_FREQ
 * @brief The frequency fed to HX711 in Hz. Values 1 - 20MHz.
 */
#ifndef LOAD_CELL_XTAL_FREQ
#define LOAD_CELL_XTAL_FREQ 20000000
#endif

/**
 * @def LOAD_CELL_XTAL_CHANNEL
 * @brief The [ESP timer channel](https://docs.espressif.com/projects/esp-idf/en/latest/esp32/api-reference/peripherals/ledc.html) used to generate the clock signal for HX711. Valid values 0-7.
 */
#ifndef LOAD_CELL_XTAL_CHANNEL
#define LOAD_CELL_XTAL_CHANNEL 0
#endif

/**
 * @def LOAD_CELL_XTAL_ENABLE_PIN
 * @brief The ESP32 pin connected to HX711 RATE pin.
 */
#ifndef LOAD_CELL_XTAL_ENABLE_PIN
#define LOAD_CELL_XTAL_ENABLE_PIN 17
#endif

/**
 * @def BATTERY_LEVEL_PIN
 * @brief The ESP32 pin used to measure the battery level.
 */
#ifndef BATTERY_LEVEL_PIN
#define BATTERY_LEVEL_PIN 4
#endif

/**
 * @def BATTERY_LEVEL_MAX_VALUE_ADC
 * @brief The ADC value ESP32 will measure when the battery is full.
 */
#ifndef BATTERY_LEVEL_MAX_VALUE_ADC
#define BATTERY_LEVEL_MAX_VALUE_ADC 2786
#endif

/**
 * @def BATTERY_LEVEL_MIN_VALUE_ADC
 * @brief The ADC value ESP32 will measure when the battery is empty.
 */
#ifndef BATTERY_LEVEL_MIN_VALUE_ADC
#define BATTERY_LEVEL_MIN_VALUE_ADC 1725
#endif

/**
 * @def BATTERY_LEVEL_CHECK_INTERVAL_MILLIS
 * @brief The interval for measuring battery level in milliseconds.
 */
#ifndef BATTERY_LEVEL_CHECK_INTERVAL_MILLIS
#define BATTERY_LEVEL_CHECK_INTERVAL_MILLIS 2000
#endif

/**
 * @def LED_RED_PIN
 * @brief The ESP32 pin connected to the red led.
 */
#ifndef LED_RED_PIN
#define LED_RED_PIN 23
#endif

/**
 * @def LED_GREEN_PIN
 * @brief
 */
#ifndef LED_GREEN_PIN
#define LED_GREEN_PIN 22
#endif

/**
 * @def LED_FADE_AMOUNT
 * @brief The value by which led intensity is altered when fading.
 */
#ifndef LED_FADE_AMOUNT
#define LED_FADE_AMOUNT 5
#endif

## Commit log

2023-05-19 migrate to esp32
2023-05-22 timer work
2023-06-08 change logo
    [bom.csv, designators.csv, electronic-hangboard-2.kicad_pcb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]
2023-06-08 update deps & install material design
2023-06-09 disable buttons when not active
2023-06-09 refactor timer
2023-06-15 Update pcb
    [electronic-hangboard.csv, electronic-hangboard.kicad_pcb, electronic-hangboard.kicad_sch]
2023-06-15 add battery level ble service
2023-06-15 update schematic fix voltage divider not connected
    [electronic-hangboard.kicad_pcb, electronic-hangboard.kicad_sch]
2023-06-15 report battery level
2023-06-15 read battery level in the app
2023-06-15 add enclosure
    [f=ma box v10.step]
2023-06-26 асдф
2023-06-27 almost getting the timer working again
2023-07-01 add timer state machine
2023-07-01 timer refactor
2023-07-12 complete and cancel timer
2023-07-12 Remove timer back button
2023-07-13 fix timer navigation
2023-07-13 change target framework
2023-07-15 fix timer complete
2023-09-24 rework the schematic using mt3608 dc-dc convert
    [bom.csv, designators.csv, electronic-hangboard-v2-panelized.kicad_pcb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]
2023-09-24 add led indicators
2023-09-24 move panelized board in folder
    [bom.csv, designators.csv, electronic-hangboard-v2-panelized.kicad_pcb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]
2023-09-25 update schematic
2023-09-25 add firmware and some hardware documentation
    [electronic-hangboard.kicad_sch]
2023-09-26 add diy modules
    [diy-modules.fzz]
2023-09-26 diy add battery monitor
    [diy-modules.fzz]
2024-02-04 live view
    [bom.csv, designators.csv, electronic-hangboard-v3-panelized.kicad_pcb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]
2024-07-30 OTA update
    [electronic-hangboard.kicad_pcb]
2024-08-28 schematic autosave
2024-08-28 schematic export
    [bom.csv, designators.csv, positions.csv]
2024-09-14 schematic checkout
